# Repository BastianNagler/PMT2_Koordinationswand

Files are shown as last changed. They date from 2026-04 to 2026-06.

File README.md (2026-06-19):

# cWall (Interactive Coordination Wall)

cWall is an interactive, reaction-based coordination wall designed as a student project for **PMT2 (Praktikum Messtechnik 2)** during the Summer Semester 2026. 

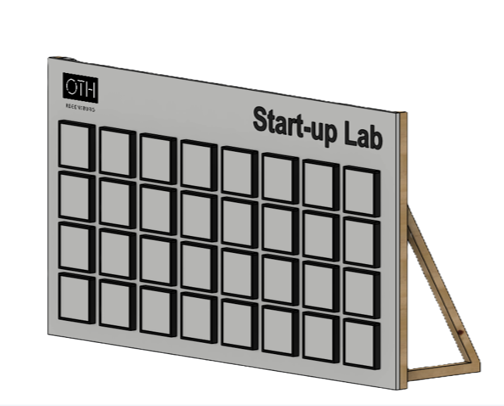
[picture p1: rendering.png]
Image of cWall


---

## Game Concept & Play Principle
The cWall is a speed and reaction game where players must trigger randomly illuminated targets as quickly as possible within a 60-second time window.

* **Sequential Progression:** Only one box lights up at a time. The moment it is successfully pressed, the next random target activates instantly.
* **Singleplayer Mode:** The player uses the entire 32-box grid to rack up the highest score possible.
* **Multiplayer Duel Mode:** The playing field is divided into two separate, independent halves (16 boxes each) for head-to-head competition.
* **Integrated Highscores:** The system automatically tracks and saves the top 10 scores persistently.

---

## Key Features
* **ESP32-S3 Control Center:** Runs a FreeRTOS-based firmware.
* **Wireless Web Dashboard:** The ESP32-S3 acts as a Wi-Fi Access Point (SSID: `C-Wall`). By connecting to the network and navigating to `192.168.1.1`, players can view live scores, a countdown timer, game status, and the highscore board in real time. Also the game settings can be adjusted via the web interface and all the logging can be accessed for debugging and performance analysis.
* **Real-time WebSockets:** Utilizes non-blocking WebSocket communication for immediate, bi-directional data transfer between the microcontroller and web browsers.
* **Modular Sensor Boxes:** 32 individual 20x20 cm 3D-printed modular sensor boxes containing internal WS2812b NeoPixel LED strips and TTP223 capacitive touch sensors.
* **Capacitive Touch Detection:** Reliable touch response through a copper-mesh grid embedded into the acrylic faceplates, connected to low-cost, self-contained TTP223 touch chips.
* **Dedicated I/O Expansion:** Employs MCP23018 I/O expanders connected via I²C to handle the high number of digital sensor inputs while conserving ESP32 pins.
* **Robust Power Delivery:** Powered by a 300W (5V/60A) switching power supply, distributed via a star topology to prevent voltage drops when LEDs display full white.
* **Custom PCB Design:** Two-sided component PCB designed using KiCad and manufactured specifically to host the level shifters, I/O expanders, and connector terminals.
* **3D-Printed Enclosures:** All sensor boxes and the main control unit are housed in custom-designed 3D-printed enclosures for durability and aesthetics.

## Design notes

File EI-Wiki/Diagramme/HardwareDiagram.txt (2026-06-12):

---
config:
  layout: dagre
---
flowchart LR
 subgraph subGraph0["Externe Steuerung"]
        Tablet["Browser"]
  end
 subgraph Zentraleinheit["ESP32"]
        ESP["ESP32-S3"]
        FS[("LittleFS Speicher<br>highscores.dat")]
  end
 subgraph subGraph2["Eingabe"]
        MCP1["MCP23018<br>IO-Expander"]
        Sensors(("Sensoren"))
  end
 subgraph subGraph3["Ausgabe"]
        LED1["WS2812b LEDs"]
        Level-Shifter["Level-Shifter"]
        StatusLED(("Heartbeat LED"))
  end
 subgraph subGraph4["I/O-Hardware"]
        subGraph2
        subGraph3
  end
    Tablet <-- WiFi Access Point<br>WebSockets --> ESP
    ESP <-- Flash Memory --> FS
    MCP1 <-- I2C --> ESP
    MCP1 --- Sensors
    ESP -- LED Data Pin --> Level-Shifter
    Level-Shifter --> LED1
    ESP -- Status Pin --> StatusLED
    MCP1 -- Hardware Interrupt --> ESP

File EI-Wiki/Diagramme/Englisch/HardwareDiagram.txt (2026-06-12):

---
config:
  layout: fixed
---
flowchart LR
 subgraph subGraph0["WebClient"]
        Tablet["Browser"]
  end
 subgraph Zentraleinheit["ESP32"]
        ESP["ESP32-S3"]
        FS[("LittleFS Memory")]
  end
 subgraph subGraph2["Input"]
        MCP1["IO-Expander"]
        Sensors(("Touch-Sensors"))
  end
 subgraph subGraph3["Output"]
        LED1["WS2812b LEDs"]
        Level-Shifter["Level-Shifter"]
        StatusLED(("Heartbeat LED"))
  end
    Sensors ---> MCP1
    Level-Shifter --> LED1
    MCP1 <-- I²C --> ESP
    MCP1 -- Hardware Interrupt --> ESP
    Tablet <-- WiFi Access Point --> ESP
    ESP <-- Flash Memory --> FS
    ESP -- LED Data Pin --> Level-Shifter
    ESP -- Status Pin --> StatusLED

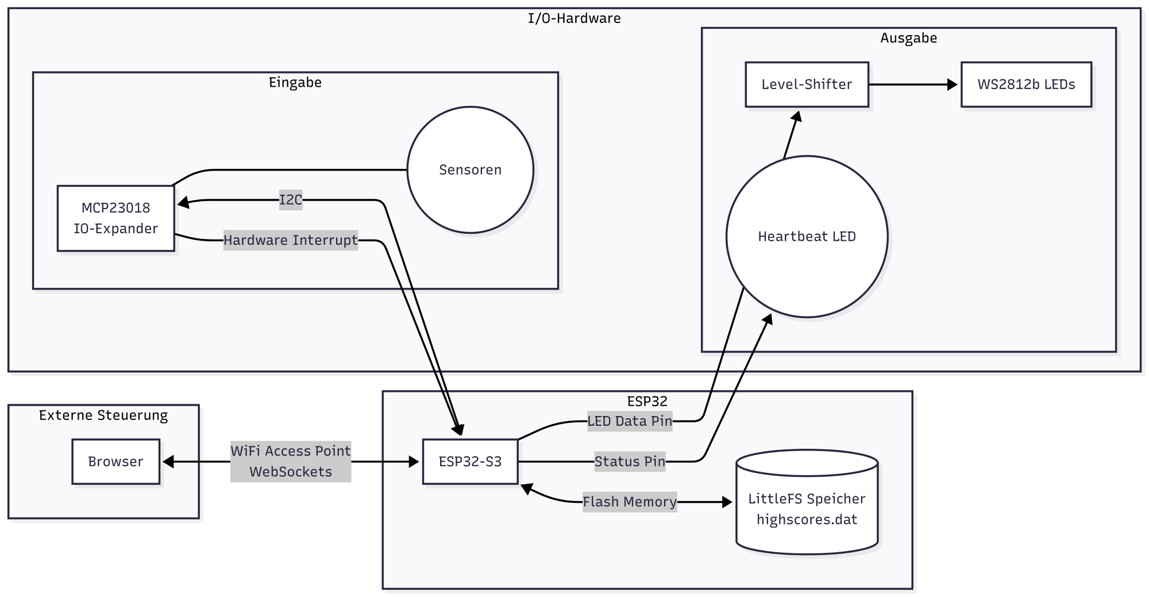
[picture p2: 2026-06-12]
EI-Wiki/Diagramme/HardwareDiagram.png

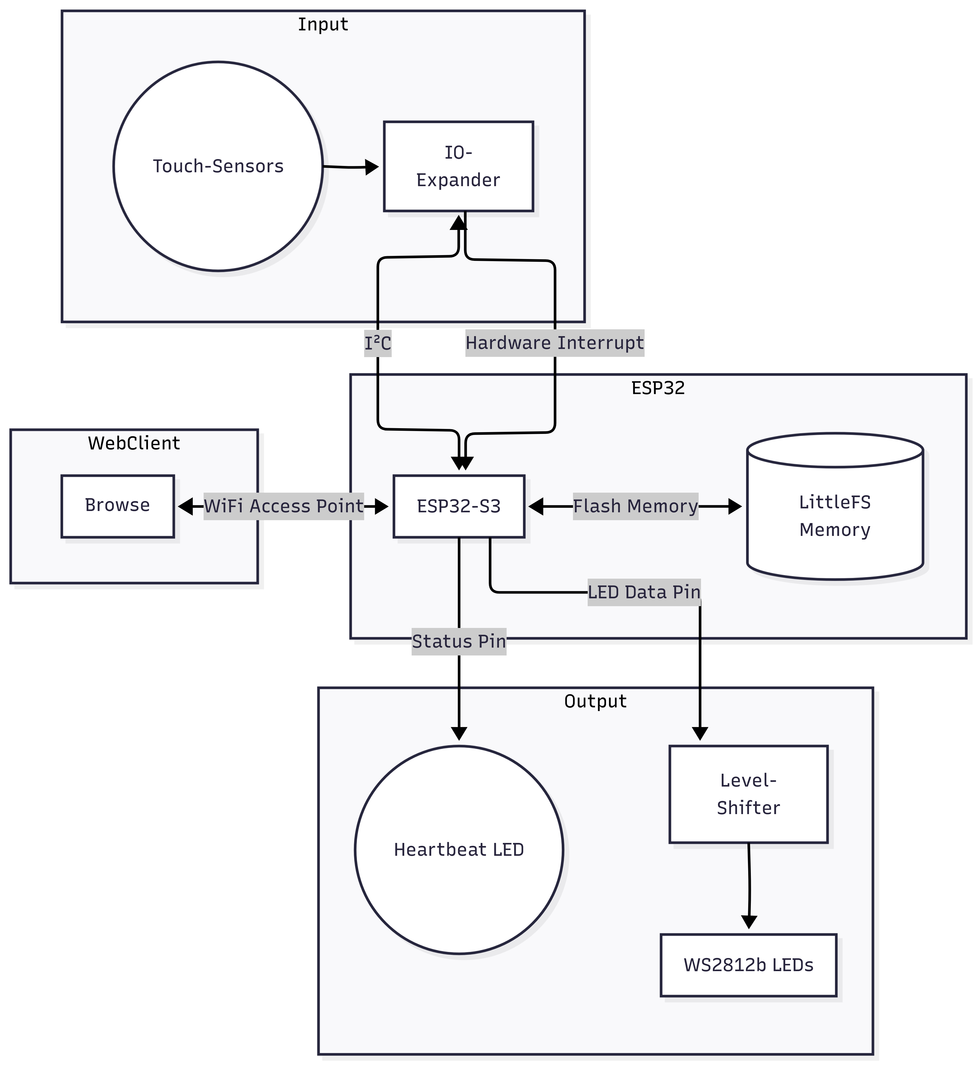
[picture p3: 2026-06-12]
EI-Wiki/Diagramme/Englisch/HardwareDiagram.png

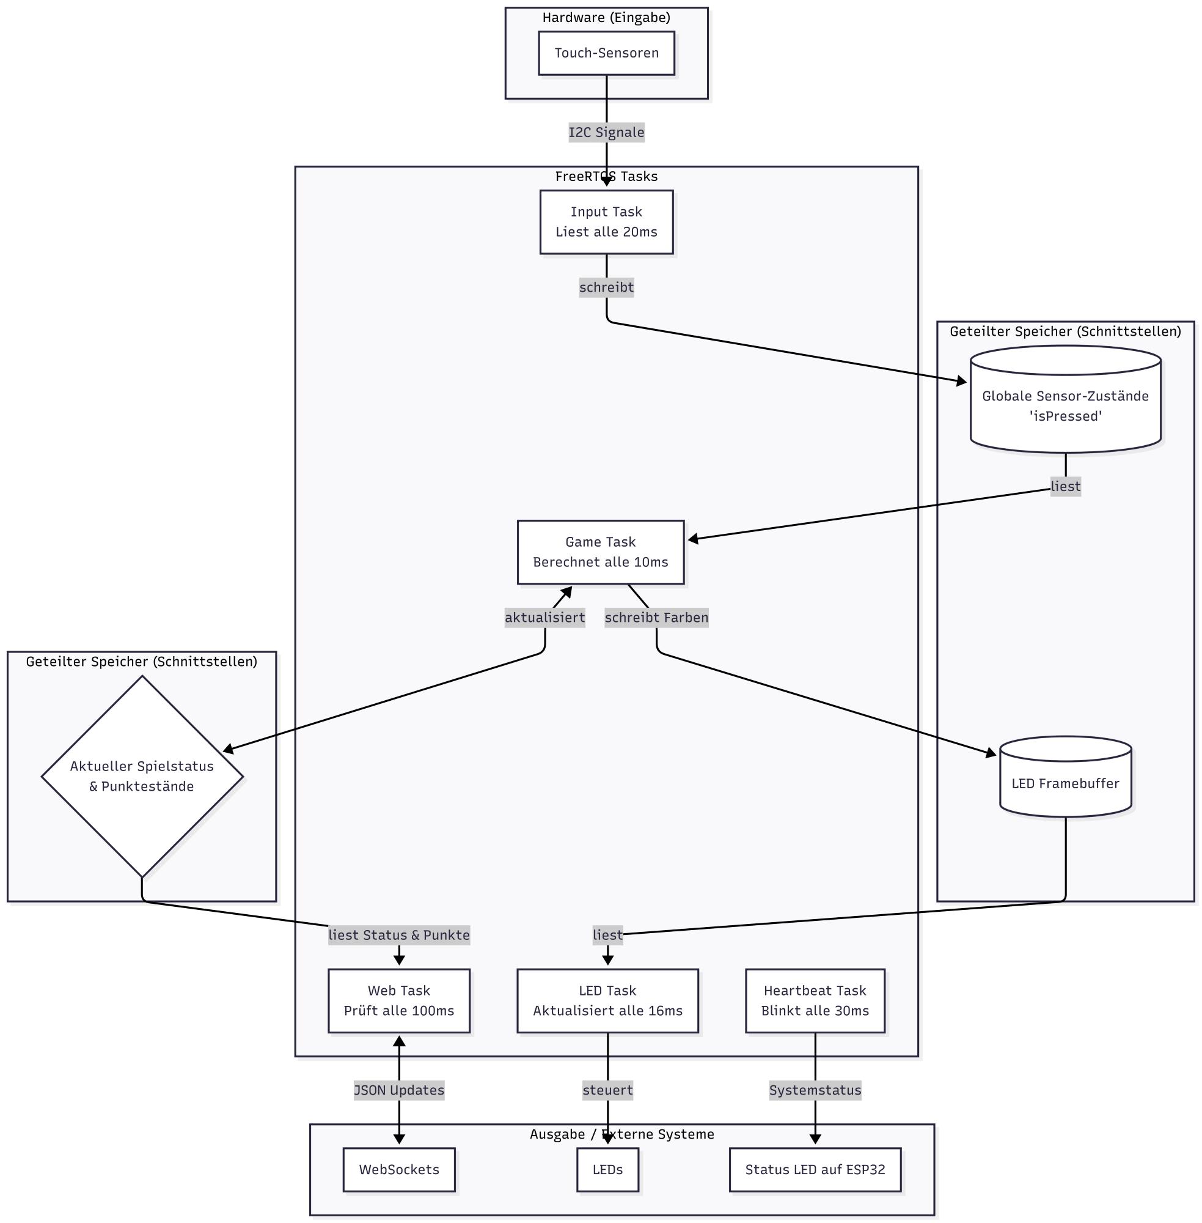
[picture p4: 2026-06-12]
EI-Wiki/Diagramme/FreeRTOS_Tasks.png

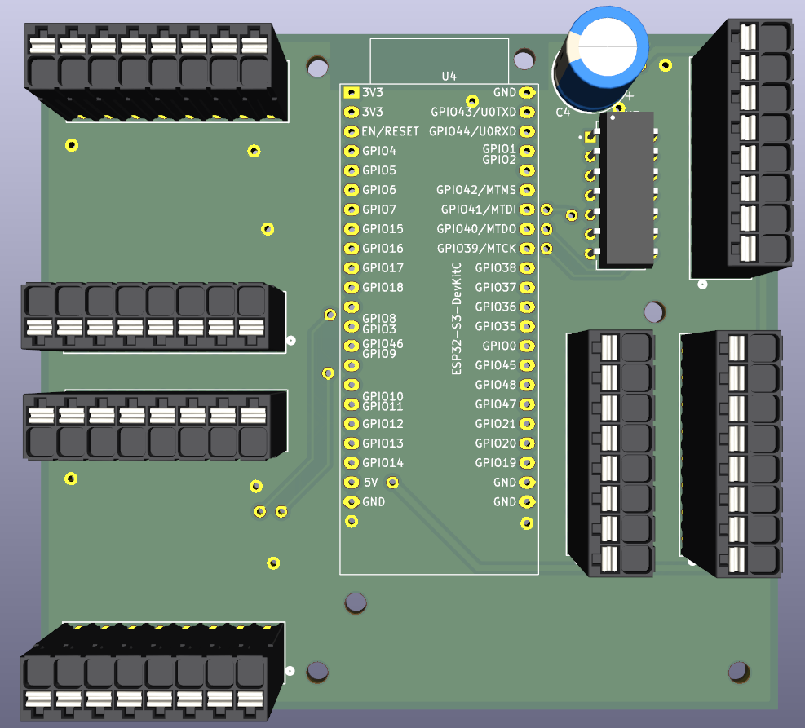
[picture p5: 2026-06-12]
EI-Wiki/Platine/Platine_oberseite.png

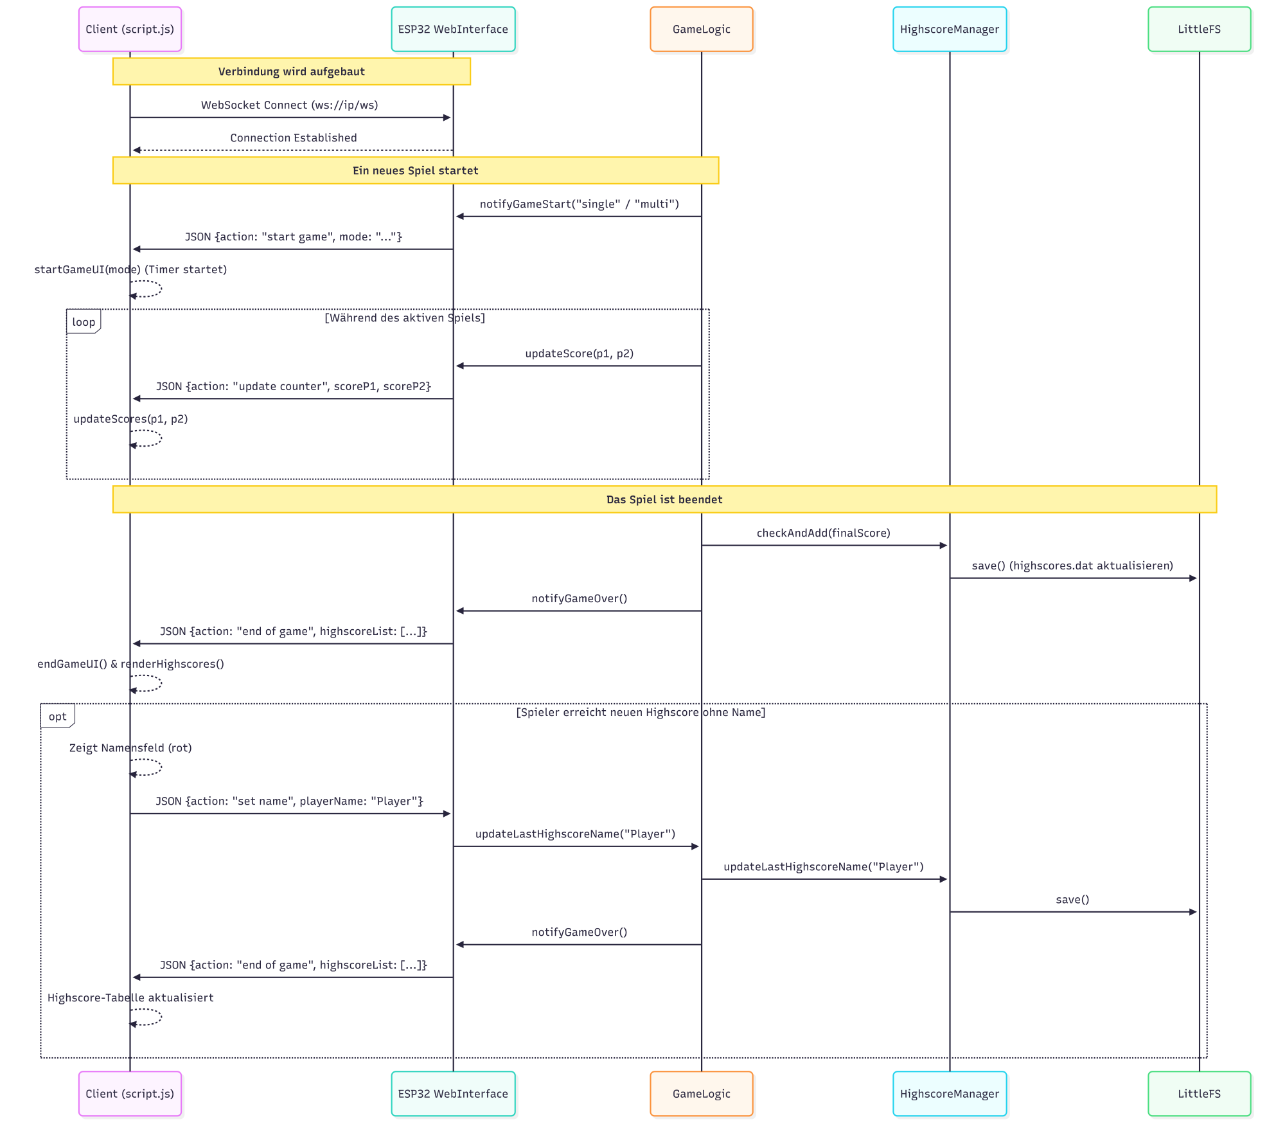
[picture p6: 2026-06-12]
EI-Wiki/Diagramme/Web_SequenceDiagram.png

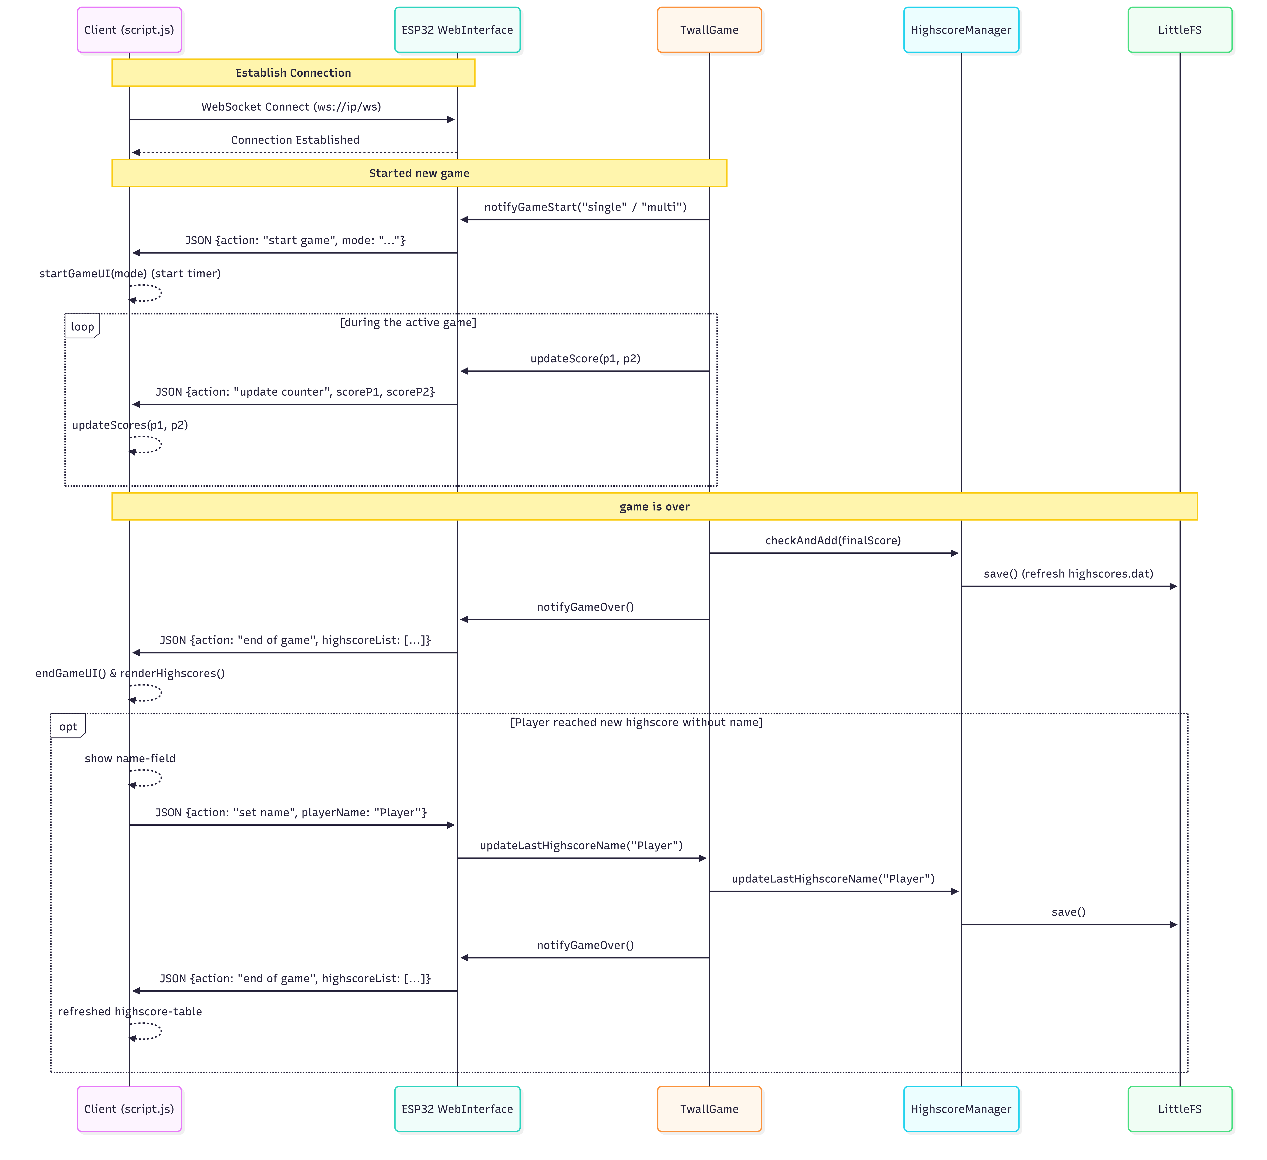
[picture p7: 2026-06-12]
EI-Wiki/Diagramme/Englisch/Web_SequenceDiagram.png

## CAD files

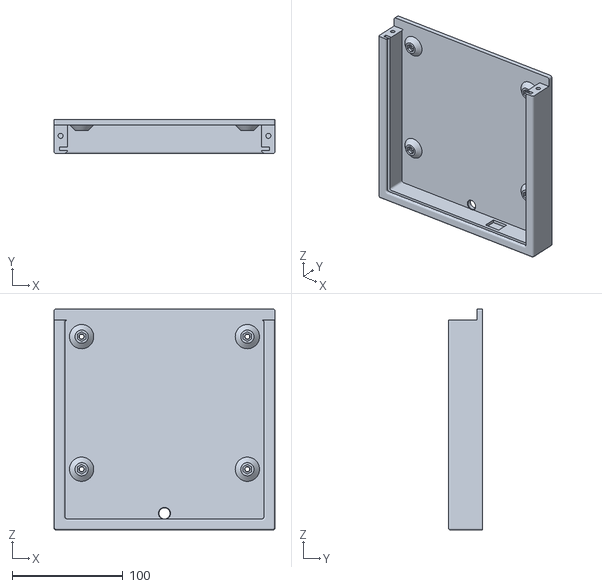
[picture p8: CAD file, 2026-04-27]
STLs/Grundkoerper_V3_Bohrung_ganz_unten.stl
200.0 x 31.2 x 200.0

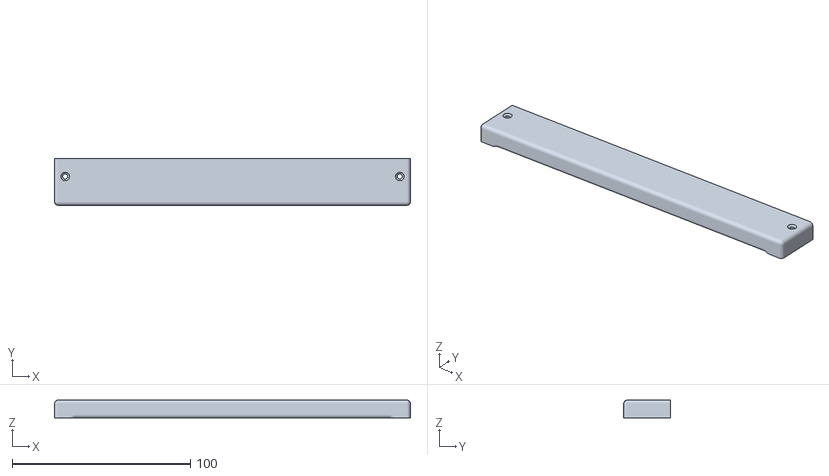
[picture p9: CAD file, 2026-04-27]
STLs/Deckel_oben_V3.stl
200.0 x 26.2 x 10.0

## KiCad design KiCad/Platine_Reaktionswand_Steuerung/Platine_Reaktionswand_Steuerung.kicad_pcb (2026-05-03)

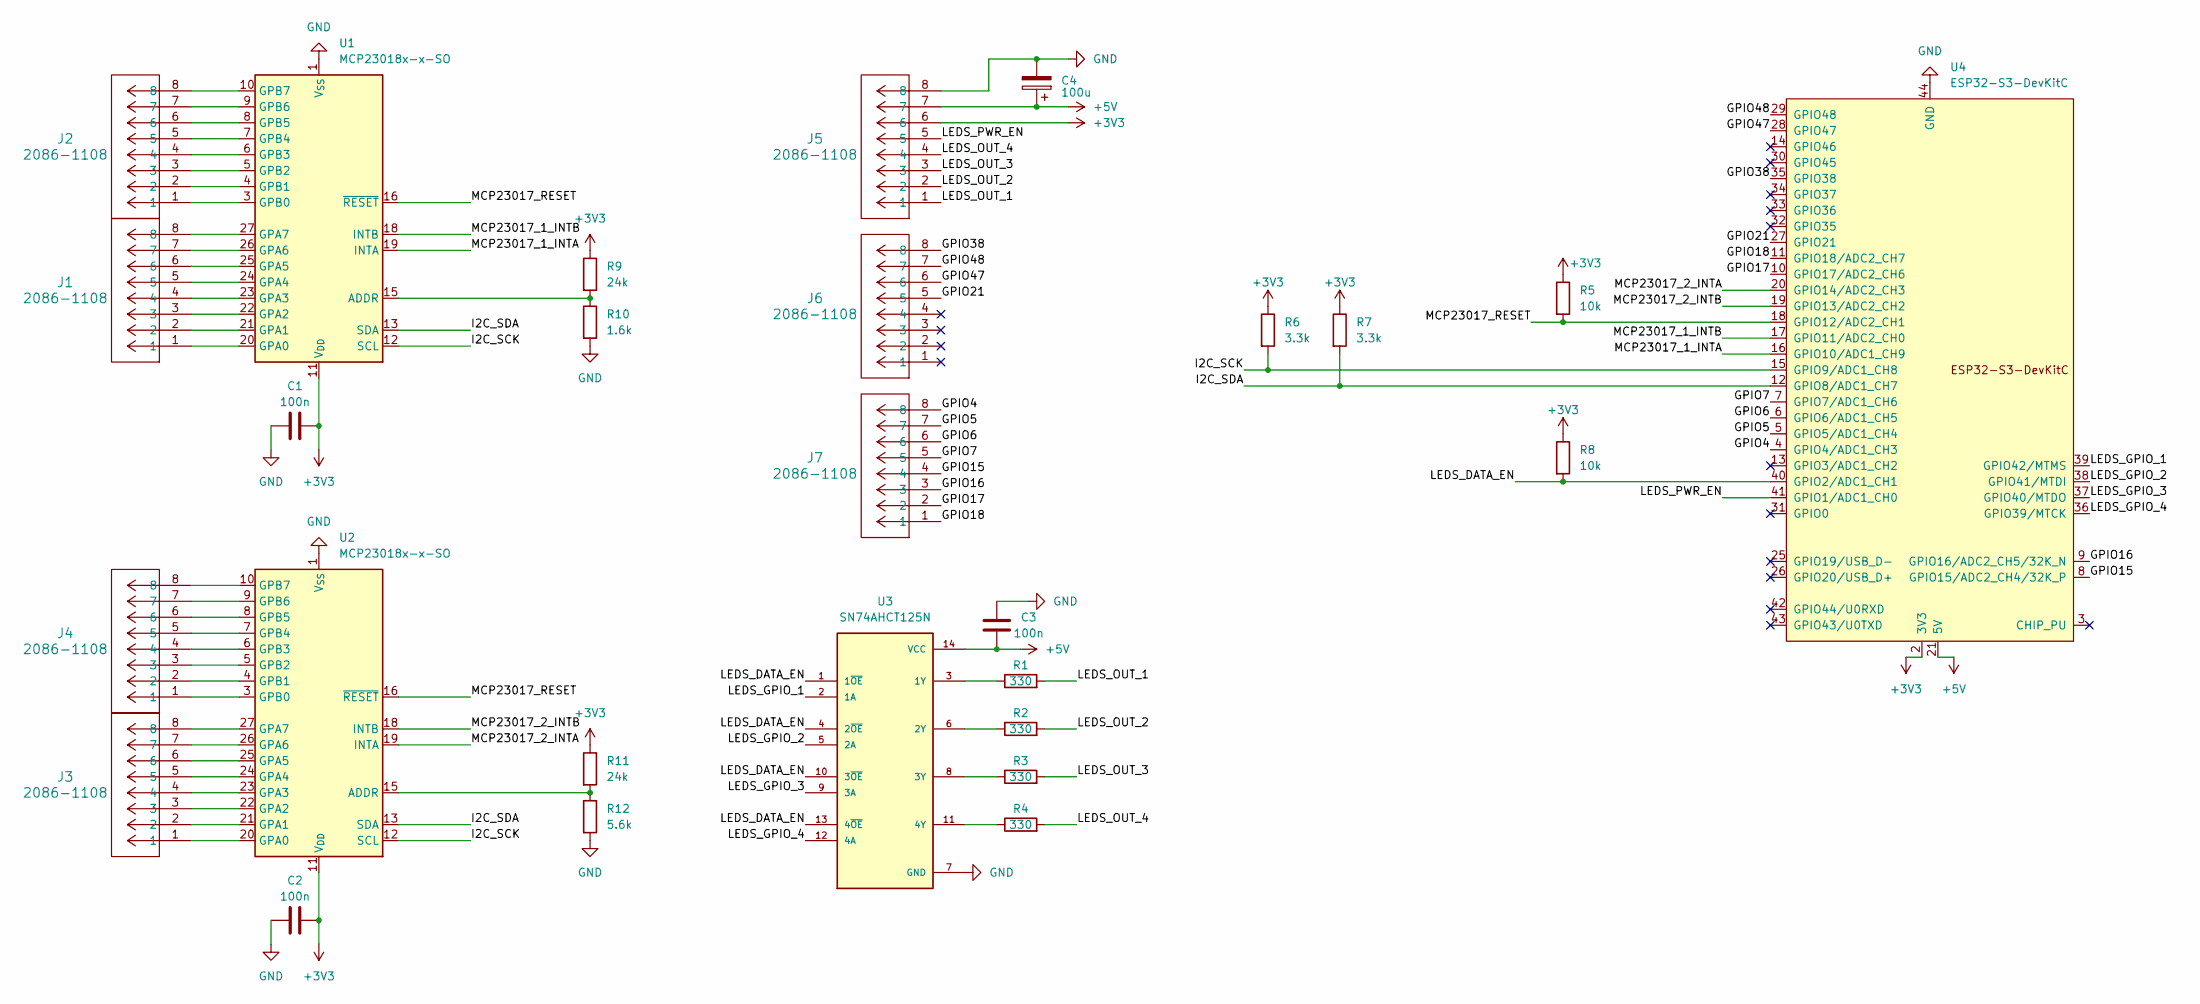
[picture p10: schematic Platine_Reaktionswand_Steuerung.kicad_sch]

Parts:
C1, C2, C3: 100n; C_0603_1608Metric_Pad1.08x0.95mm_HandSolder
C4: 100u; CP_Radial_D10.0mm_P5.00mm
J1, J2, J3, J4, J5, J6, J7: 2086-1108; LCSC C3309486
R1, R2, R3, R4: 330; R_0603_1608Metric_Pad0.98x0.95mm_HandSolder
R5, R8: 10k; R_0603_1608Metric_Pad0.98x0.95mm_HandSolder
R6, R7: 3.3k; R_0603_1608Metric_Pad0.98x0.95mm_HandSolder
R9, R11: 24k; R_0603_1608Metric_Pad0.98x0.95mm_HandSolder
R10: 1.6k; R_0603_1608Metric_Pad0.98x0.95mm_HandSolder
R12: 5.6k; R_0603_1608Metric_Pad0.98x0.95mm_HandSolder
U1, U2: MCP23018x-x-SO; SOIC-28W_7.5x17.9mm_P1.27mm
U3: SN74AHCT125N; SN74HCT125N; PARTREV Q; LCSC C354152
U4: ESP32-S3-DevKitC

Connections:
+3V3: C1.1, C2.1, J5.6, R5.1, R6.1, R7.1, R8.1, R9.1, R11.1, U1.11 (V_{DD}), U2.11 (V_{DD}), U4.1 (3V3), U4.2 (3V3)
+5V: C3.2, C4.1, J5.7, U3.14 (VCC), U4.21 (5V)
/GPIO4: J7.8, U4.4 (GPIO4/ADC1_CH3)
/GPIO5: J7.7, U4.5 (GPIO5/ADC1_CH4)
/GPIO6: J7.6, U4.6 (GPIO6/ADC1_CH5)
/GPIO7: J7.5, U4.7 (GPIO7/ADC1_CH6)
/GPIO15: J7.4, U4.8 (GPIO15/ADC2_CH4/32K_P)
/GPIO16: J7.3, U4.9 (GPIO16/ADC2_CH5/32K_N)
/GPIO17: J7.2, U4.10 (GPIO17/ADC2_CH6)
/GPIO18: J7.1, U4.11 (GPIO18/ADC2_CH7)
/GPIO21: J6.5, U4.27 (GPIO21)
/GPIO38: J6.8, U4.35 (GPIO38)
/GPIO47: J6.6, U4.28 (GPIO47)
/GPIO48: J6.7, U4.29 (GPIO48)
/I2C_SCK: R6.2, U1.12 (SCL), U2.12 (SCL), U4.15 (GPIO9/ADC1_CH8)
/I2C_SDA: R7.2, U1.13 (SDA), U2.13 (SDA), U4.12 (GPIO8/ADC1_CH7)
/LEDS_DATA_EN: R8.2, U3.1 (1~OE), U3.4 (2~OE), U3.10 (3~OE), U3.13 (4~OE), U4.40 (GPIO2/ADC1_CH1)
/LEDS_GPIO_1: U3.2 (1A), U4.39 (GPIO42/MTMS)
/LEDS_GPIO_2: U3.5 (2A), U4.38 (GPIO41/MTDI)
/LEDS_GPIO_3: U3.9 (3A), U4.37 (GPIO40/MTDO)
/LEDS_GPIO_4: U3.12 (4A), U4.36 (GPIO39/MTCK)
/LEDS_OUT_1: J5.1, R1.2
/LEDS_OUT_2: J5.2, R2.2
/LEDS_OUT_3: J5.3, R3.2
/LEDS_OUT_4: J5.4, R4.2
/LEDS_PWR_EN: J5.5, U4.41 (GPIO1/ADC1_CH0)
/MCP23017_1_INTA: U1.19 (INTA), U4.16 (GPIO10/ADC1_CH9)
/MCP23017_1_INTB: U1.18 (INTB), U4.17 (GPIO11/ADC2_CH0)
/MCP23017_2_INTA: U2.19 (INTA), U4.20 (GPIO14/ADC2_CH3)
/MCP23017_2_INTB: U2.18 (INTB), U4.19 (GPIO13/ADC2_CH2)
/MCP23017_RESET: R5.2, U1.16 (~RESET), U2.16 (~RESET), U4.18 (GPIO12/ADC2_CH1)
GND: C1.2, C2.2, C3.1, C4.2, J5.8, R10.2, R12.2, U1.1 (V_{SS}), U2.1 (V_{SS}), U3.7 (GND), U4.22 (GND), U4.23 (GND), U4.24 (GND), U4.44 (GND)
unnamed: R9.2, R10.1, U1.15 (ADDR)
unnamed: J1.1, U1.20 (GPA0)
unnamed: J1.2, U1.21 (GPA1)
unnamed: J1.3, U1.22 (GPA2)
unnamed: J1.4, U1.23 (GPA3)
unnamed: J1.5, U1.24 (GPA4)
unnamed: J1.6, U1.25 (GPA5)
unnamed: J1.7, U1.26 (GPA6)
unnamed: J1.8, U1.27 (GPA7)
unnamed: J2.1, U1.3 (GPB0)
unnamed: J2.2, U1.4 (GPB1)
unnamed: J2.3, U1.5 (GPB2)
unnamed: J2.4, U1.6 (GPB3)
unnamed: J2.5, U1.7 (GPB4)
unnamed: J2.6, U1.8 (GPB5)
unnamed: J2.7, U1.9 (GPB6)
unnamed: J2.8, U1.10 (GPB7)
unnamed: R11.2, R12.1, U2.15 (ADDR)
unnamed: J3.1, U2.20 (GPA0)
unnamed: J3.2, U2.21 (GPA1)
unnamed: J3.3, U2.22 (GPA2)
unnamed: J3.4, U2.23 (GPA3)
unnamed: J3.5, U2.24 (GPA4)
unnamed: J3.6, U2.25 (GPA5)
unnamed: J3.7, U2.26 (GPA6)
unnamed: J3.8, U2.27 (GPA7)
unnamed: J4.1, U2.3 (GPB0)
unnamed: J4.2, U2.4 (GPB1)
unnamed: J4.3, U2.5 (GPB2)
unnamed: J4.4, U2.6 (GPB3)
unnamed: J4.5, U2.7 (GPB4)
unnamed: J4.6, U2.8 (GPB5)
unnamed: J4.7, U2.9 (GPB6)
unnamed: J4.8, U2.10 (GPB7)
unnamed: R1.1, U3.3 (1Y)
unnamed: R2.1, U3.6 (2Y)
unnamed: R3.1, U3.8 (3Y)
unnamed: R4.1, U3.11 (4Y)

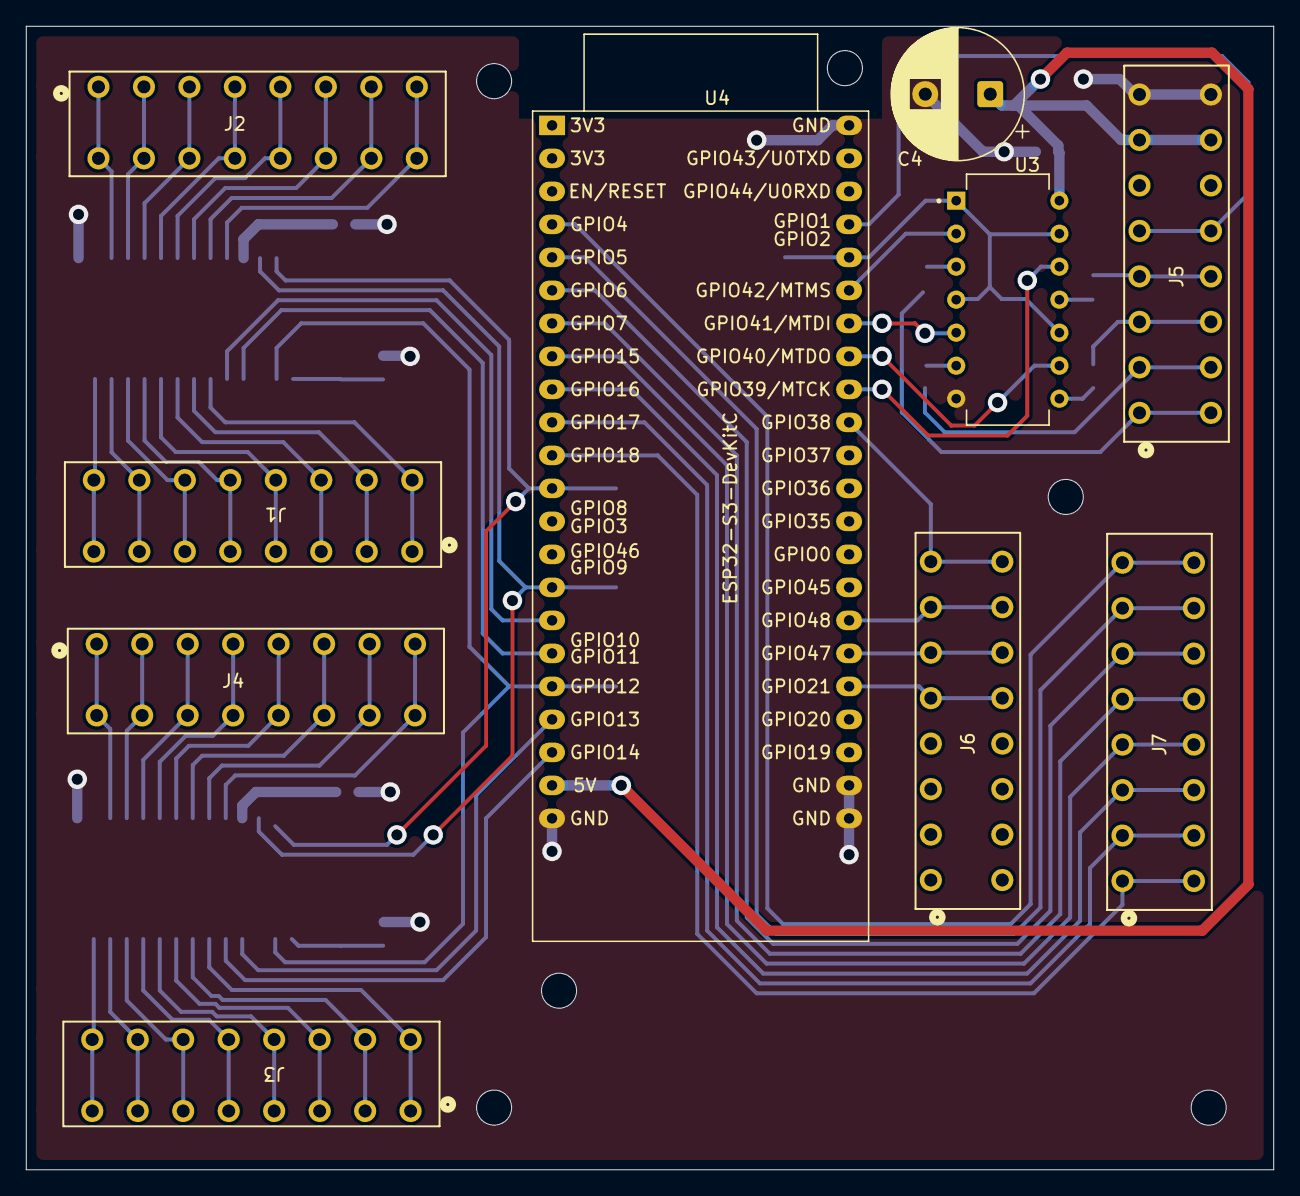
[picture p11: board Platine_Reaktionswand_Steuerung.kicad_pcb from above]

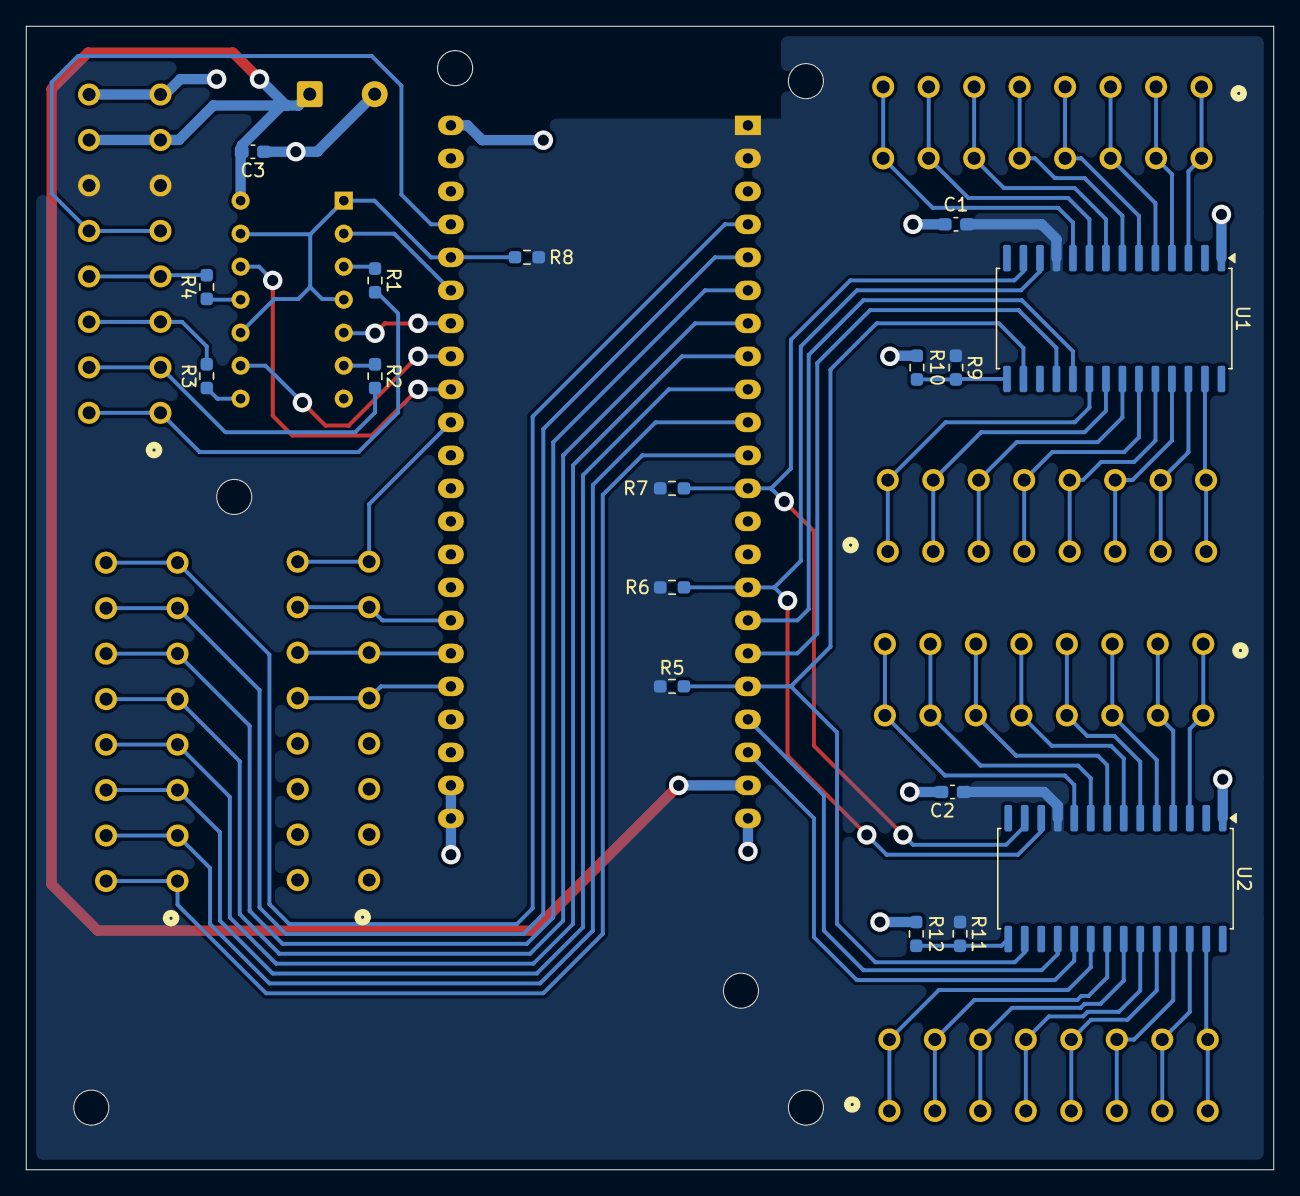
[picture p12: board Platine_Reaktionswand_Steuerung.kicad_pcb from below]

Board: 2 copper layers, 96.0 x 88.0 mm, 27 parts (17 on the bottom side), 70 nets.

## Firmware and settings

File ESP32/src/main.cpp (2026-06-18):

#include <Arduino.h>
#include <Wire.h>
#include <esp_timer.h>
#include <esp_task_wdt.h>
#include <LittleFS.h>

#include "GameLogic.h"
#include "config.h"
#include "leds.h"
#include "ioExpander.h"
#include "heartbeat.h"
#include "WebInterface.h"
#include "WebLog.h"

volatile bool isPressed[NUM_FIELDS];
LED_Driver leds;
HeartbeatLED heartbeat;
GameLogic gameInstance(isPressed, leds);

void inputTask(void *pvParameters);
void gameTask(void *pvParameters);
void webTask(void *pvParameters);
void ledTask(void *pvParameters);
void heartbeatTask(void *pvParameters);

// --- Custom Panic Handler ---
void custom_panic_handler(arduino_panic_info_t *info, void *arg) {
    ws2812Write(HEARTBEAT_LED_PIN, 0x00FF00); 
}

void setup()
{
    delay(500);
    Serial.begin(115200);

    // Initialize LittleFS once at startup
    if (!LittleFS.begin(true))
    {
        WebLog.println("[ERROR] LittleFS mounting failed during setup!");
    }
    else
    {
        WebLog.println("[SETUP] LittleFS mounted successfully.");
    }

    // Recover the I2C bus if stuck before starting communication
    recoverI2CBus(I2C_SDA_PIN, I2C_SCL_PIN);

    Wire.begin(I2C_SDA_PIN, I2C_SCL_PIN, 400000);
    Wire.setTimeOut(100);

    set_arduino_panic_handler(custom_panic_handler, NULL);

    xTaskCreate(ledTask, "LED Task", 4096, NULL, 4, NULL);
    xTaskCreatePinnedToCore(inputTask, "Input Task", 4096, NULL, 3, NULL, 1);
    xTaskCreate(gameTask, "Game Task", 4096, NULL, 2, NULL);
    xTaskCreate(webTask, "Web Task", 8192, NULL, 1, NULL);
    xTaskCreate(heartbeatTask, "Heartbeat Task", 2048, NULL, 0, NULL);
    vTaskDelete(NULL);
}

/// @brief Task for handling hardware inputs. High priority to ensure responsiveness.
void inputTask(void *pvParameters) 
{
    static const uint8_t io_exp_irq_pins[NUM_IO_EXPANDER] = IO_EXPANDER_IRQ_PINS;
    static const uint8_t io_exp_addresses[NUM_IO_EXPANDER] = IO_EXPANDER_ADDRESSES;
    static IO_Expander expanders(NUM_IO_EXPANDER, io_exp_addresses, io_exp_irq_pins);

    if (!expanders.init())
    {
        heartbeat.setError();
    }

    /*
    dirty fix because PCB broke for Box index 16: read box over GPIO18
    if PCB gets fixed: delete following line and connect Sensor 16 back to IO-Expander
    */
    pinMode(18, INPUT);

    esp_task_wdt_add(NULL);

    while (1) {
        if (!expanders.read(isPressed, NUM_FIELDS))
        {
            WebLog.println("[ERROR] IO-Expander read failed! Resetting MCP23018s...");
            heartbeat.setError();
            if (expanders.resetAndReinit())
            {
                WebLog.println("[IO-EXPANDER] MCP23018s reset and re-initialized successfully.");
            }
            else
            {
                WebLog.println("[ERROR] Failed to re-initialize MCP23018s after reset.");
            }
        }

        /*
        dirty fix because PCB broke for Box index 16: read box over GPIO18
        if PCB gets fixed: delete following line and connect Sensor 16 back to IO-Expander
        */
        if(NUM_FIELDS >= 17)
            isPressed[16] = digitalRead(18);

        esp_task_wdt_reset();
        vTaskDelay(pdMS_TO_TICKS(10));
    }
}

/// @brief Task for running game logic 
void gameTask(void *pvParameters)
{
    esp_task_wdt_add(NULL);
    
    gameInstance.init();

    while(1)
    {
        gameInstance.run(millis());

        esp_task_wdt_reset();
        vTaskDelay(pdMS_TO_TICKS(10));
    }
}

/// @brief Task for running Web-Server 
void webTask(void *pvParameters)
{
    static GameState lastGameState = IDLE;
    static uint8_t lastScoreP1 = 0;
    static uint8_t lastScoreP2 = 0;

    initWebInterface();
    while(1)
    {
        GameState currentState = gameInstance.getGameState();
        GameMode currentMode = gameInstance.getGameMode();
        uint8_t scoreP1 = gameInstance.getScoreP1();
        uint8_t scoreP2 = gameInstance.getScoreP2();
        
        cleanupWebInterface();

        // --- 1. Check for status-change (Start / End) ---
        if (currentState != lastGameState) {
            if (currentState == PLAYING && lastGameState != RIPPLE_ANIM) {
                notifyGameStart(currentMode == SINGLE_PLAYER ? "single" : "multi");
                lastScoreP1 = 0;
                lastScoreP2 = 0;
            } else if (currentState == GAME_OVER || currentState == COOLDOWN) {
                notifyGameOver();
            }
            lastGameState = currentState;
        }

        // --- 2. Check for score updates ---
        if (currentState == PLAYING) {
            if (scoreP1 != lastScoreP1 || scoreP2 != lastScoreP2) {
                updateScore(scoreP1, scoreP2);
                lastScoreP1 = scoreP1;
                lastScoreP2 = scoreP2;
            }
        }

        vTaskDelay(pdMS_TO_TICKS(100));
    }
}

/// @brief Task for updating the LEDs
void ledTask(void *pvParameters) 
{
    esp_task_wdt_add(NULL);
    leds.init();
    while (1)
    {
        leds.show();

        esp_task_wdt_reset();
        vTaskDelay(pdMS_TO_TICKS(16));
    }
}

/// @brief Task for updating the Heartbeat-LED 
void heartbeatTask(void *pvParameters)
{
    while(1)
    {
        heartbeat.update();
        vTaskDelay(pdMS_TO_TICKS(30));
    }
}

void loop() 
{
    // This function is no longer used.
}

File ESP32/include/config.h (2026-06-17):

#pragma once


// ###################
//     SOFTWARE
// ###################

#define NUM_ROWS 4 // MAX 4
#define NUM_COLUMNS 8
#define NUM_FIELDS (NUM_ROWS * NUM_COLUMNS)

#define MAX_BRIGHTNESS 255 // Adjust brightness as needed, 0-255
#define NUM_LEDS_PER_FIELD 16
#define NUM_LEDS (NUM_FIELDS * NUM_LEDS_PER_FIELD)

#define NUM_IO_EXPANDER 2
#define NUM_IO_PER_EXPANDER 16



// ###################
//     HARDWARE
// ###################

#define LED_DRIVER_0_PIN 42
#define LED_DRIVER_1_PIN 41
#define LED_DRIVER_2_PIN 40
#define LED_DRIVER_3_PIN 39

#define HEARTBEAT_LED_PIN 38

#define I2C_SCL_PIN 9
#define I2C_SDA_PIN 8
#define IO_EXPANDER_ADDRESSES {0x20, 0x21} // Change to actual addresses
#define IO_EXPANDER_IRQ_PINS {10, 14} // Change to actual pins
#define IO_EXPANDER_RESET_PIN 12

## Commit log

2026-03-06 Added support for Fields in LED_Driver and added RGB_Color class
2026-03-09 Added working Project for 1st Prototype
2026-03-09 updated LED_Driver to use allocated array instead of std::vector
2026-03-11 Fixed minor issue in LED_Driver (wrong constant used in set_led_in_field)
2026-03-11 EOD 11.03
    [T-Wall.kicad_pcb, T-Wall.kicad_sch]
2026-03-12 PCB Revision 1
2026-03-12 PCB Revision 2
    [T-Wall.kicad_pcb, T-Wall.kicad_sch]
2026-03-13 EOD 1303
    [T-Wall.kicad_pcb, T-Wall.kicad_sch]
2026-03-13 added KiCad libraries to repo
2026-03-16 changed KiCad libraries to project-specific libraries
    [T-Wall.kicad_pcb, T-Wall.kicad_sch]
2026-03-16 added ESP32 Software to repo
2026-03-17 just some BWL things...
    [T-Wall.kicad_pcb, T-Wall.kicad_sch, bom.csv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]
2026-03-18 Finished BWL-rebuild
    [T-Wall.kicad_pcb, T-Wall.kicad_sch, bom.csv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]
2026-03-29 added 3D-print files for a single box
    [Deckel_oben.3mf, Deckel_oben.stl, Grundkörper.3mf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]
2026-03-29 fixed correct define for FastLED to use I2S
    [config.h, main.cpp]
2026-03-29 fixed false fix for FastLED to use I2S (testing is important)
    [main.cpp]
2026-03-29 added 100 nF capacitor for the level-shifter
    [T-Wall.kicad_pcb, T-Wall.kicad_sch]
2026-03-29 PCB QOL: changed sizes to 0603 and moved vias away from pads
    [T-Wall.kicad_pcb, T-Wall.kicad_sch]
2026-03-30 irgendwas schaltplan
    [T-Wall.kicad_sch]
2026-03-30 PCB: routed unused GPIOs to Pins
    [T-Wall.kicad_pcb, T-Wall.kicad_sch]
2026-04-06 deleted config for non-WS2812b LEDs
2026-04-07 PCB: corrected WAGO footprint
    [T-Wall.kicad_pcb]
2026-04-09 PCB: added fuse and reverse-polarity-protection
    [T-Wall.kicad_pcb, T-Wall.kicad_sch, bom.csv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]
2026-04-11 PCB: overvoltage-protection and optimized routing
    [T-Wall.kicad_pcb, T-Wall.kicad_sch]
2026-04-11 PCB: upgraded KiCad to 10.0.1
    [T-Wall.kicad_pcb, T-Wall.kicad_sch]
2026-04-12 PCB: finished for purchase at JLCPCB
    [T-Wall.kicad_pcb, T-Wall.kicad_sch, bom.csv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]
2026-04-18 cleared warning for MCP23017 driver
2026-04-19 added led-driver as a HAL
2026-04-19 changed pin-config for use with test-breadboard
2026-04-27 Added final STLs and the Bambu Studio Project
    [Deckel_oben_V3.stl, Grundkoerper_V3_Bohrung_ganz_unten.3mf, Grundkoerper_V3_Bohrung_ganz_unten.stl]
2026-05-03 final Bambu Studio project file with best results
    [Grundkoerper_V3_Bohrung_ganz_unten.3mf]
2026-05-03 PCB: changed PCB from JLCPCB-version to OTH-version
    [Platine_Reaktionswand_Steuerung-B_Cu.gbr, Platine_Reaktionswand_Steuerung-Edge_Cuts.gbr, Platine_Reaktionswand_Steuerung-F_Cu.gbr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]
2026-05-04 changed config to work with PCB
2026-05-04 fixed bug: retry search for IO-Expander when it isnt found
    [MCP23018.cpp]
2026-05-05 added the LED_DATA_EN pin functionality
2026-05-05 added a heartbeat LED and a Error-Check for every I2C action
    [MCP23018.cpp, config.h, ioExpander.cpp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]
2026-05-27 minor changes for stability and added ripple-animation
    [TwallGame.cpp]
2026-05-27 added watchdog-timer
2026-05-28 fixed task_watchdog issue and stack overflow for the Input-Task
    [main.cpp]
2026-05-28 optimized heartbeat.update to only update the OnBoard-LED
2026-05-28 fixed main to working RTOS
    [main.cpp]
2026-06-03 change Heartbeat-LED to use bitbanging to not run out of Hardware-Drivers
2026-06-03 fixed webserver bug gamestate
    [main.cpp]
2026-06-03 added box 16 read and hopefully fixed buggy leds
    [main.cpp]
2026-06-03 added a cutom panic-handler to set the status led to red if panic happens
2026-06-12 deleted old and unused files and added ducomentation pictures and diagrams
    [Deckel_oben.3mf, Deckel_oben.stl, Deckel_oben_V3.stl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]
2026-06-17 fixed IO-Expander issues with incorrect initialization and automatic reset
    [MCP23018.cpp, config.h, ioExpander.cpp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]
2026-06-17 added improved i2c check
2026-06-17 prohibit the first targets to be the start-buttons
2026-06-17 added improved i2c errer handling
2026-06-17 fixed error with improved i2c error handling
    [MCP23018.cpp]
2026-06-17 added i2c-bus recovery at setup
2026-06-17 deleted KiCad history subrepo
2026-06-18 changed Landing Page
